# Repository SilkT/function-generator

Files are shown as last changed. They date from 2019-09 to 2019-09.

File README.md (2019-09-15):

# function-generator
A function generator with variable frequency and different typical signals to choose from(sine, triangle, saw and square).
the project is based on STM32F051K8 microcontroller which features built-in DAC. Shematics and layout were designed using Autodesk Eagle software. For the most part shematics were designed according to datasheets of used components. The resulting analog signal is ‘cleaned’ from high frequency component with calculated passive low-pass filter.
Software part of the project was executed in C using STM32Cube for configuration and Keil µVision as IDE. Project uses standard HAL drivers and own code for digital-to-analog processing with wavetables generated in Matlab, that are converted to analog values on the output of device. Modified OpenSource library is used for indication on the OLED screen.
Software still needs a lot of tuning, but that's just a part of a bigger project involving DSP on low-end STM32 MCUs so I'm working on it ;)

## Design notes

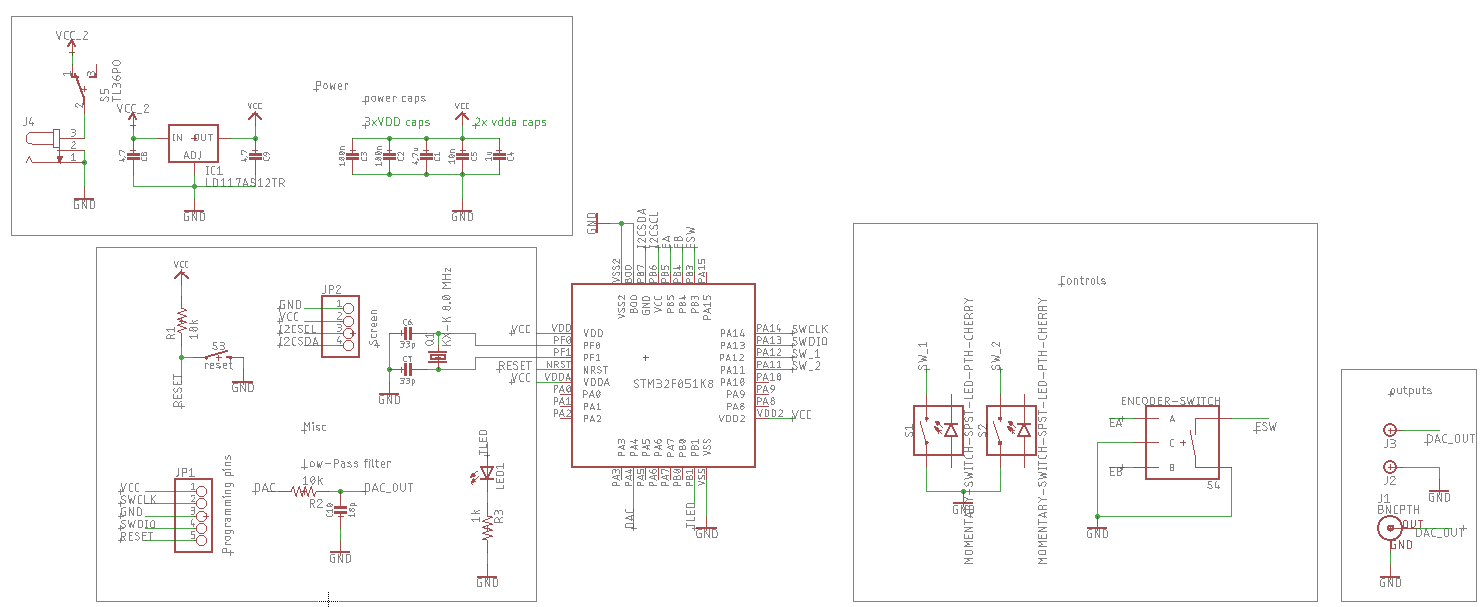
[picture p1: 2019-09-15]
hardware/eagle_2019-09-15_22-59-42.png

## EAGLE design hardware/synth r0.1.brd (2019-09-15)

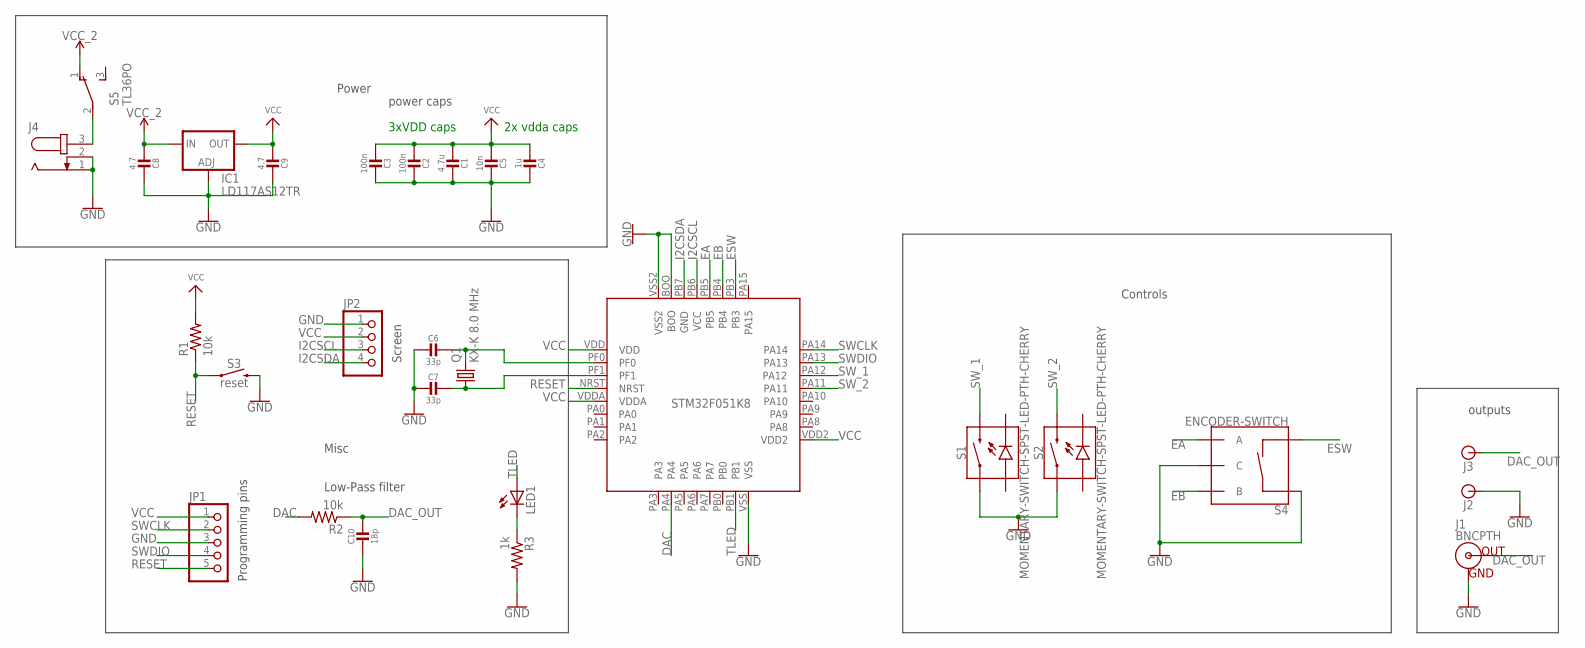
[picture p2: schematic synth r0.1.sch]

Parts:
C1: 4.7u; 0805-NO
C2, C3: 100n; 0805-NO
C4: 1u; 0805-NO
C5: 10n; 0805-NO
C6, C7: 33p; 0805-NO
C8, C9: 4.7; 0805-NO
C10: 18p; 0805-NO
IC1: LD117AS12TR; SOT223
J1: BNCPTH; BNC
J2, J3: BANANA_CONN
J4: JACK-PLUG1; SPC4078
JP1: PINHD-1X5; 1X05
JP2: PINHD-1X4; 1X04
LED1: LEDCHIPLED_0805; CHIPLED_0805
Q1: KX-K 8.0 MHz; HC49/S
R1, R2: 10k; R0805
R3: 1k; R0805
S1, S2: MOMENTARY-SWITCH-SPST-LED-PTH-CHERRY; CHERRY-MX-LED
S3: reset; TACTILE_SWITCH_SMD_5.2MM
S4: ENCODER-SWITCH; ROTARY_ENC_PLAIN
S5: TL36PO; TL3XPO
U$1: STM32F051K8; LQFP32-7X7

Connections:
DAC: R2.2, U$1.PA4
DAC_OUT: C10.1, J1.S (OUT), J3.P$1, R2.1
EA: S4.A, U$1.PB5
EB: S4.B, U$1.PB4
ESW: S4.SW-, U$1.PB3
GND: C1.1, C2.1, C3.1, C4.1, C5.1, C6.2, C7.2, C8.1, C9.1, C10.2, IC1.1 (ADJ), J1.GND, J2.P$1, J4.1, J4.2, JP1.3, JP2.1, R3.2, S1.S1 (1), S2.S1 (1), S3.3 (2), S3.4 (2), S4.C, S4.SW+, U$1.BOO, U$1.VSS, U$1.VSS2
I2CSCL: JP2.3, U$1.PB6
I2CSDA: JP2.4, U$1.PB7
unnamed: C6.1, Q1.2, U$1.PF0
unnamed: C7.1, Q1.1, U$1.PF1
unnamed: J4.3, S5.2
unnamed: LED1.C, R3.1
PA0: U$1.PA0
PA7: U$1.PA7
PB0: U$1.PB0
RESET: JP1.5, R1.1, S3.1, S3.2 (1), U$1.NRST
SWCLK: JP1.2, U$1.PA14
SWDIO: JP1.4, U$1.PA13
SW_1: S1.S2 (2), U$1.PA12
SW_2: S2.S2 (2), U$1.PA11
TLED: LED1.A, U$1.PB1
VCC: C1.2, C2.2, C3.2, C4.2, C5.2, C9.2, IC1.4 (OUT), JP1.1, JP2.2, R1.2, U$1.VDD, U$1.VDD2, U$1.VDDA
VCC_2: C8.2, IC1.3 (IN), S5.1 (O)

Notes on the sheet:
3xVDD caps
2x vdda caps
power caps
Power
outputs
Misc
Controls
Programming pins
Low-Pass filter
Screen

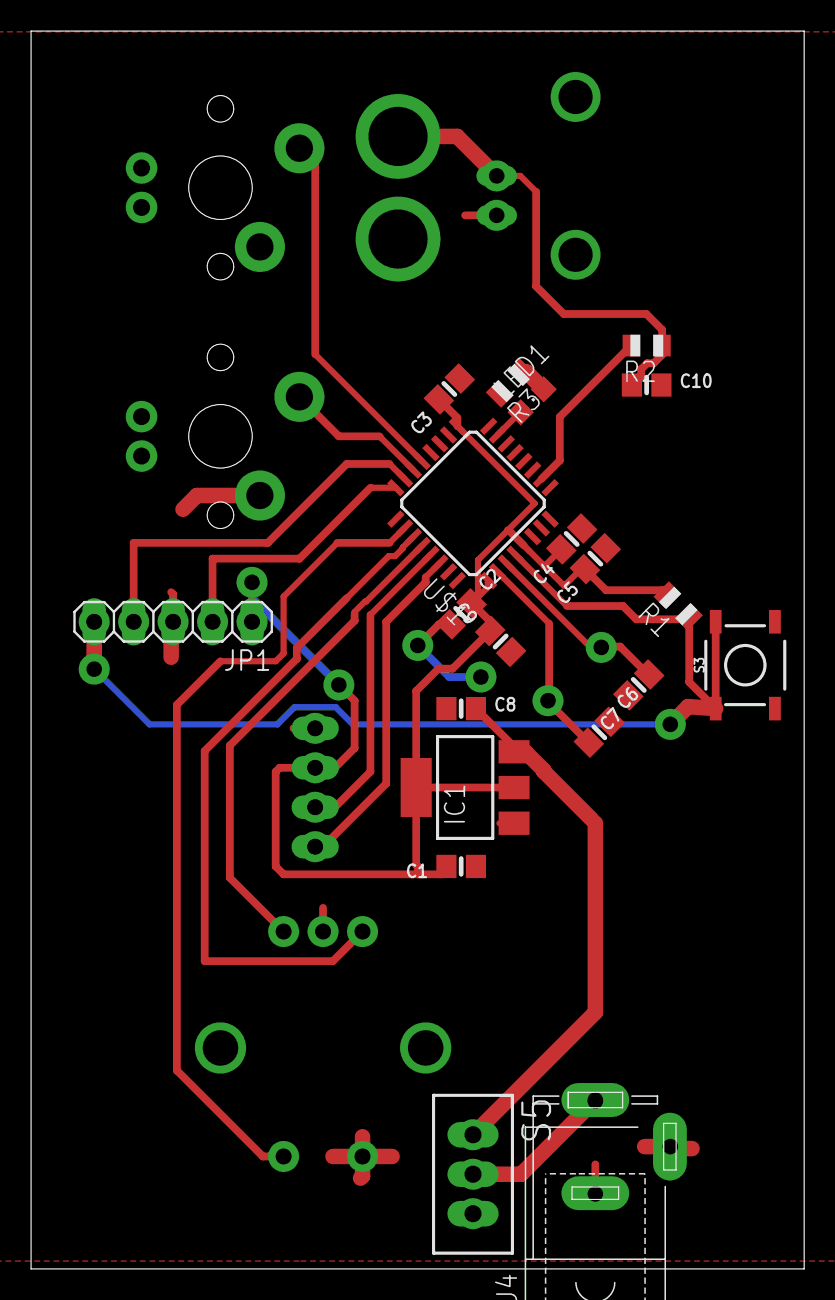
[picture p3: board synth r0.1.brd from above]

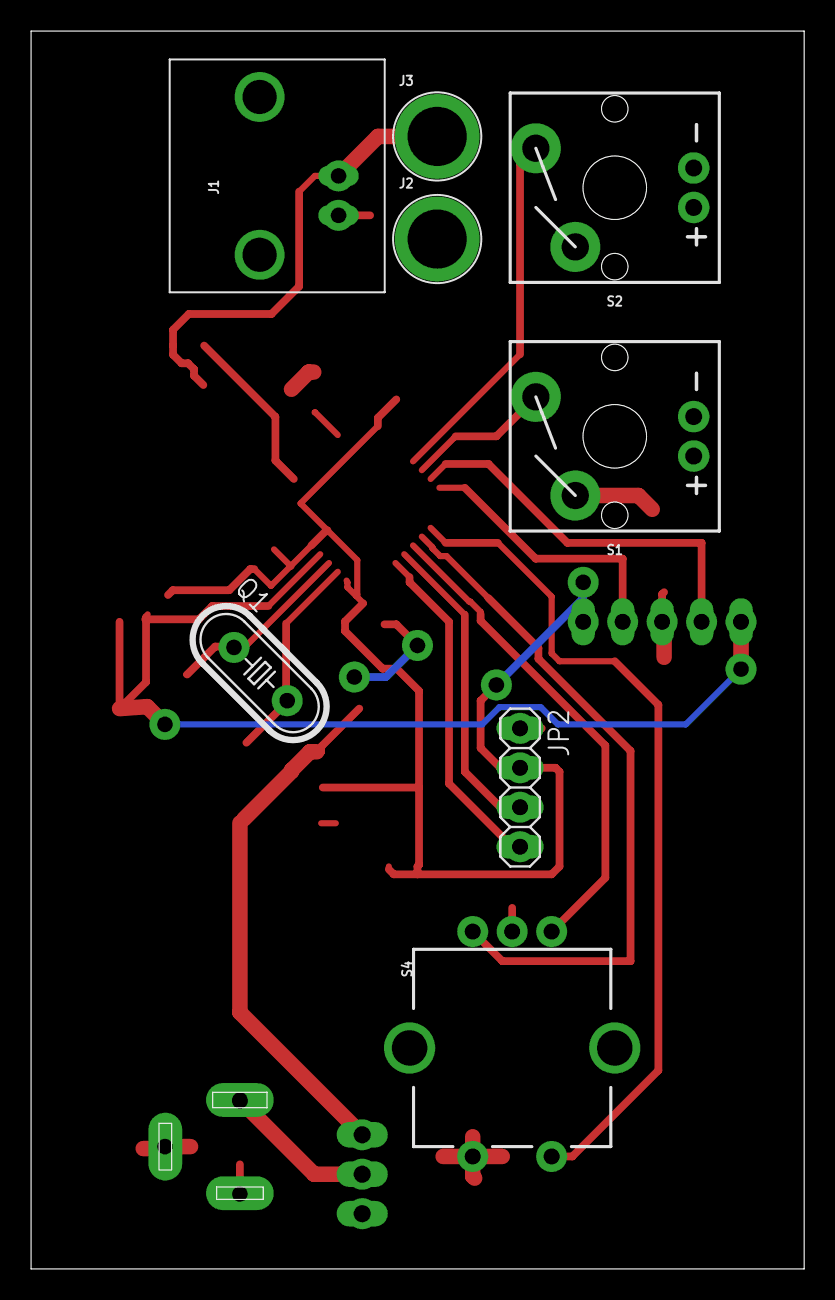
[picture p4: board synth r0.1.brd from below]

Board: 2 copper layers, 49.8 x 79.7 mm, 28 parts (8 on the bottom side), 20 nets.

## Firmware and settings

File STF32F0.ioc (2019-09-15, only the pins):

Mcu.UserName=STM32F051K8Tx
PA11.Signal=GPIO_Input
PA12.Signal=GPIO_Input
PA13.Signal=SYS_SWDIO
PA14.Signal=SYS_SWCLK
PA4.Signal=COMP_DAC11_group
PB1.Signal=GPIO_Output
PB3.Signal=GPIO_Input
PB4.Signal=GPIO_Input
PB5.Signal=GPIO_Input
PB6.Signal=I2C1_SCL
PB7.Signal=I2C1_SDA
PF0-OSC_IN.Signal=RCC_OSC_IN
PF1-OSC_OUT.Signal=RCC_OSC_OUT

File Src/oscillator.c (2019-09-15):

#include "stm32f0xx_hal.h"
#include "oscillator.h"
#include "wavetables.h"
uint16_t freq;
DAC_Waveform_t current_waveform;
void DAC_Osc_Init() {
	HAL_TIM_Base_Start(&HTIMx);
	HAL_DAC_Start_DMA(&hdac1, DAC_CH, (uint32_t*)sine_table_32, 32, DAC_ALIGN_12B_R);
	TIMx->ARR = TIM_F / (32*1000);
    current_waveform = DAC_SineWave;
    freq=1000;
}
void DAC_Set_Wave(DAC_Waveform_t waveform) {
	if (waveform != current_waveform){
	current_waveform = waveform;
	switch (current_waveform)
		{
		case DAC_SineWave:
			HAL_DAC_Stop_DMA(&hdac1, DAC_CH);
			HAL_DAC_Start_DMA(&hdac1, DAC_CH, (uint32_t*)sine_table_32, 32, DAC_ALIGN_12B_R);
			break;

		case DAC_TriWave:
			HAL_DAC_Stop_DMA(&hdac1, DAC_CH);
			HAL_DAC_Start_DMA(&hdac1, DAC_CH, (uint32_t*)triangle_table_32, 32, DAC_ALIGN_12B_R);
			break;

		case DAC_SawWave:
			HAL_DAC_Stop_DMA(&hdac1, DAC_CH);
			HAL_DAC_Start_DMA(&hdac1, DAC_CH, (uint32_t*)saw_table_32, 32, DAC_ALIGN_12B_R);
			break;

		default:
			HAL_DAC_Stop_DMA(&hdac1, DAC_CH);
			HAL_DAC_Start_DMA(&hdac1, DAC_CH, (uint32_t*)sine_table_32, 32, DAC_ALIGN_12B_R);
			break;
		}
	}
}

void DAC_Change_Frequency(uint16_t f){
	freq = f;
    if(current_waveform!=DAC_SqrWave){
        TIMx->ARR = TIM_F / (32*freq);
    }
}

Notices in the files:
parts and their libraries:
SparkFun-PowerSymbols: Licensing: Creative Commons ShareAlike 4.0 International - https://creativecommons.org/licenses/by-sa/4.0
